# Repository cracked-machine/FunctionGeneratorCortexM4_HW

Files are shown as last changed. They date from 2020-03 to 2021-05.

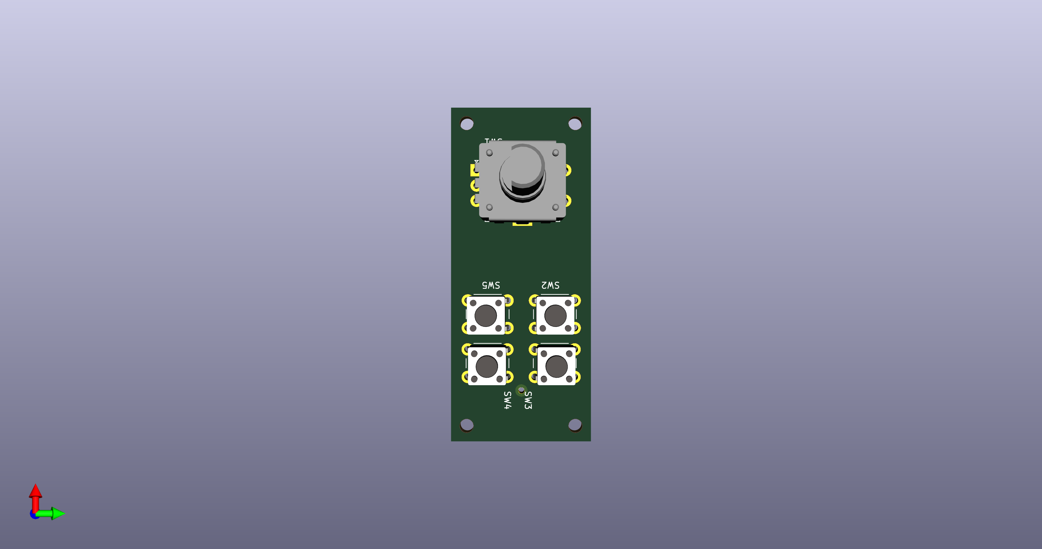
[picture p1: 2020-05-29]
HW/ControlsBoard/RevE/ControlsBoard/ControlsBoard.png

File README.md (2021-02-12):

## Cortex M4-based Function Generator (Hardware)
A function generator powered by STM32 G4.

Required Kicad Hardware library: https://github.com/cracked-machine/KicadLibrary

For details of the MCU configuration and firmware refer to [FunctionGeneratorCortexM4_SW](https://github.com/cracked-machine/FunctionGeneratorCortexM4_SW)

Note, RevB was the final design. RevC was not built and is an untested future proposal. 

### System Overview

Input signals can be used as a trigger, capturing on voltage level or edge detection.

DAC1 synthesises the main output signal waveform and sends it to a voltage gain amplifier ([LTC6910-3](https://www.analog.com/media/en/technical-documentation/data-sheets/6910fb.pdf)). The signal is then mixed with the DC offset signal from DAC2. The signal is then passes through a lowpass filter to remove any high frequency noise.

DAC2 is a DC signal 0-3.3V. This is sent to a buffer and inverting buffer. Either output is selected using the MCU-controlled SPDT switch IC ([TS12A12511DCNR](http://www.ti.com/lit/ds/symlink/ts12a12511.pdf)). This applies a software configurable DC offset between +3.3V and -3.3V to the main output signal.

DAC3 is an output signal synchronised to DAC1 to be used for triggering purposes.



### Daughter boards ###

The display, controls and i/o connectors are connected via daughter boards to the main board via ribbon cable. An example of the display daughter board and its ribbon cable can be seen in the video below:

https://www.instagram.com/p/CA5NSdBhmBY/?utm_source=ig_web_copy_link

### Power supply

##### Current Consumption:

|Component|Type|Current|
|---|----|---|
|STM32G4|MCU|42mA (max)|
|TL972|OPAMP|3.2mA (per amplifier)|
|LTC6910-3|PGA|4.9mA|
|TS12A12511|SPDT|1uA|
|74LVC1G3157|SPDT|35uA|
|LCD TFT|display|60mA|
|*__Total__*||*__120mA__*|

The 9V input is regulated down to 3.3V and 5V for the MCU and LCD display.

Dual supply for the VGA and opamps are provided using multiple [TPS60400](http://www.ti.com/lit/ds/symlink/tps60402.pdf) charge pumps. TPS60400 are rated at 60mA output but in testing was found to be less. Therefore, multiple TPS60400 were required to provide "point-of-load" regulation.

Additional filtering is provided at the MCU supply pins with L1 and L2 ferrite beads and C1-C12 bypass capacitors.

A midpoint reference 2.5V voltage is provided to the LTC6910-3 VGA using a  [TL431DBZ](https://www.ti.com/lit/ds/symlink/tl431.pdf) precision programmable reference.



### Limitations

The power supply limits the output to 9Vp-p. The output swing of the VGA limits this further.

The VGA output current is limited to ~25mA. This is also limited by the power supply.

Due to the settling time of the VGA, smooth sweeps between output amplitude levels using this IC was not possible. As such, the output is fixed to the maximum VGA level. Output amplitude control was handled by the firmware instead.

See [LTC6910-3](https://www.analog.com/media/en/technical-documentation/data-sheets/6910fb.pdf) datasheet for more information.

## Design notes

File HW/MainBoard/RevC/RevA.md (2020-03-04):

<link href="style.css" rel="stylesheet"></link>
<details>
<summary>
  <b>Functional requirements</b>
</summary>

- Output waveforms

  - Sine (wave table)
  - Step (varied DC according to step settings)
  - Square (toggled GPIO)
  - Triangle (DAC generator)
  - Sawtooth (DAC generator)
  - Pulse
  - PWM
  - Random/WhiteNoise (DAC generator)

- ~Output waveform MUX/switch to redirect output from MCU pins to Output BNC connector (if needed)~

- Output waveform frequency adjust (using rotary encoder)

- Output waveform DC bias adjust with ext. dual supply PGA (using rotary encoder)

- Output waveform gain/attenuation adjust (using rotary encoder)

- ~Redirect output to internal digital filter (FMAC)~

- Display to show active output waveform and attributes (frequency, DC bias, amplitude, relative gain)

- Input BNC connector for control voltage (to set the output waveform amplitude, trigger the output waveform)

- Output BNC connector for output waveform. 50Ω impedance.

</details>

<details>
<summary>
  <b>Top Level Design</b>
</summary>
  <p><center></p>
</details>

<details>
<summary>
  <b>PSU Component</b>
</summary>
  <p><center></p>
</details>

<details>
<summary>
  <b>Analog Front End Component</b>
</summary>
  <p><center></p>
</details>

<details>
<summary>
  <b>Schematic</b>
</summary>
  <p><a href="schema/FunctionGeneratorCortexM4.pdf">PDF Link</a></p>
<p><center></p>
<p><center></p>
<p><center></p>
<p><center></p>
</details>

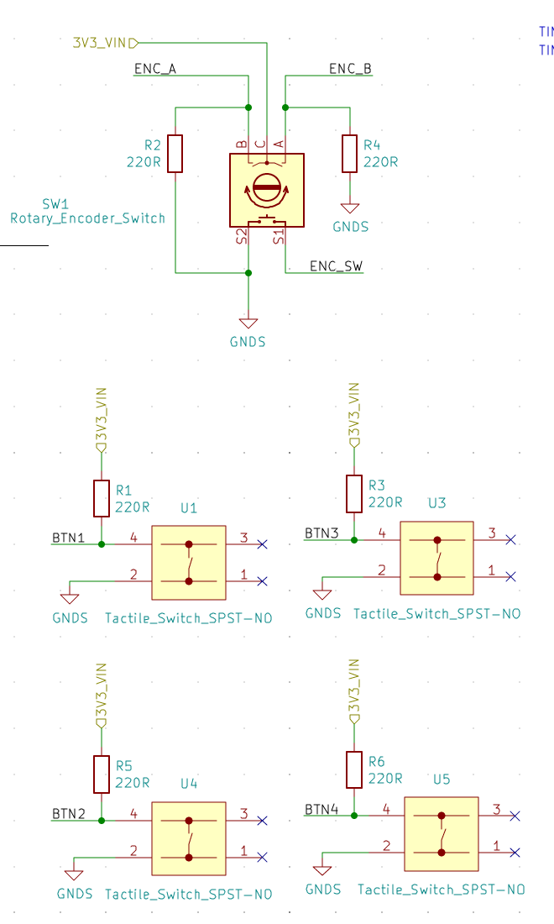
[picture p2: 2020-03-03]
FrontPanelInterface.png

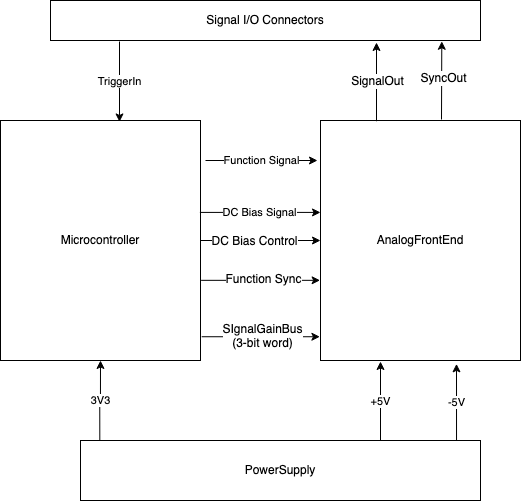
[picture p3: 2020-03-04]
HW/MainBoard/RevC/diagrams/FunctionGeneratorM4_TopLevel.png

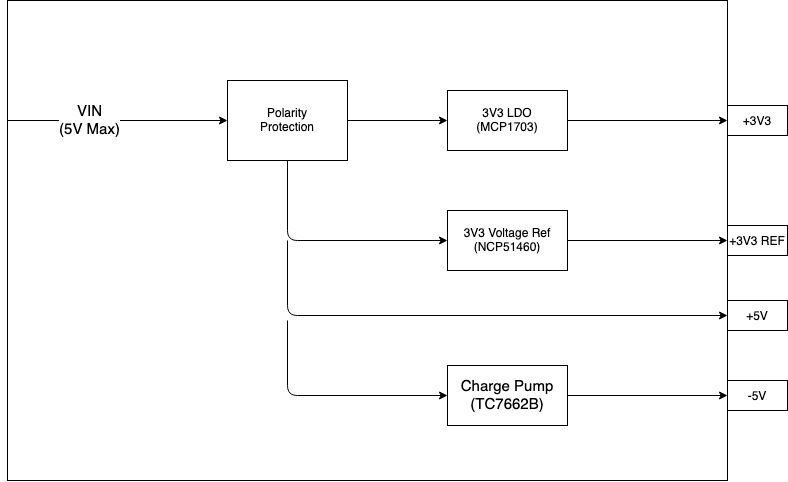
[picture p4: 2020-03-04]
HW/MainBoard/RevC/diagrams/FunctionGeneratorM4_PSU.png

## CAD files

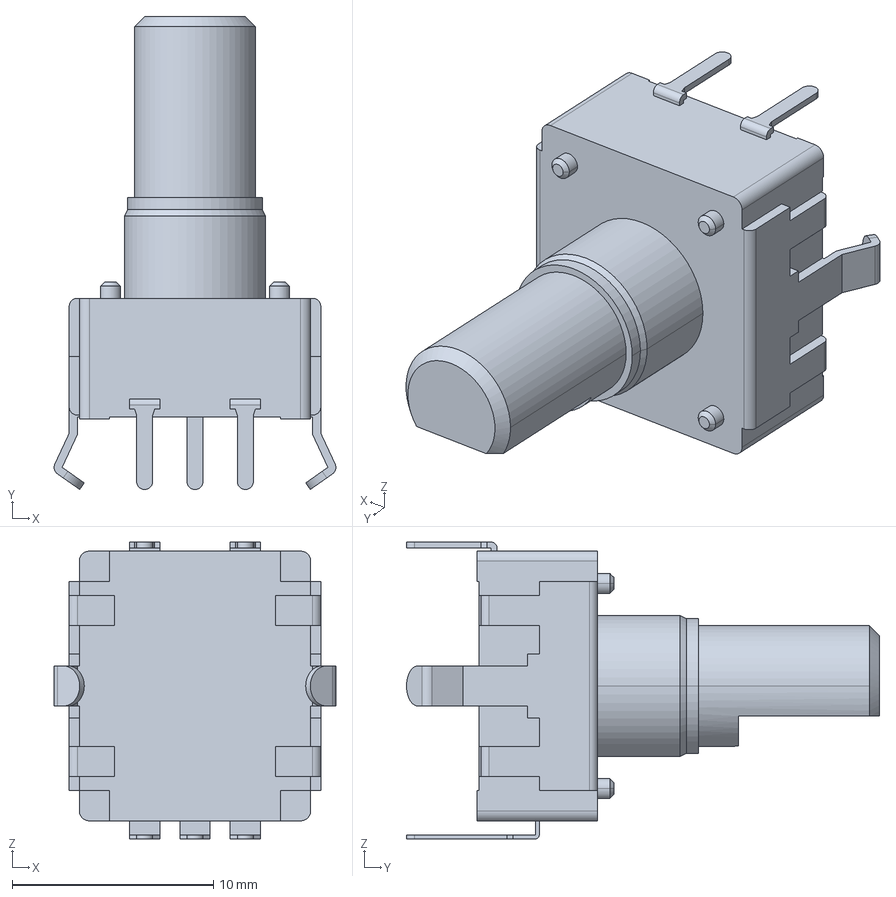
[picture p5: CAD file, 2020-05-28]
HW/ControlsBoard/RevE/ControlsBoard/pec12r-4x20f-sxxxx.stp
14.0 x 23.5 x 14.7 mm

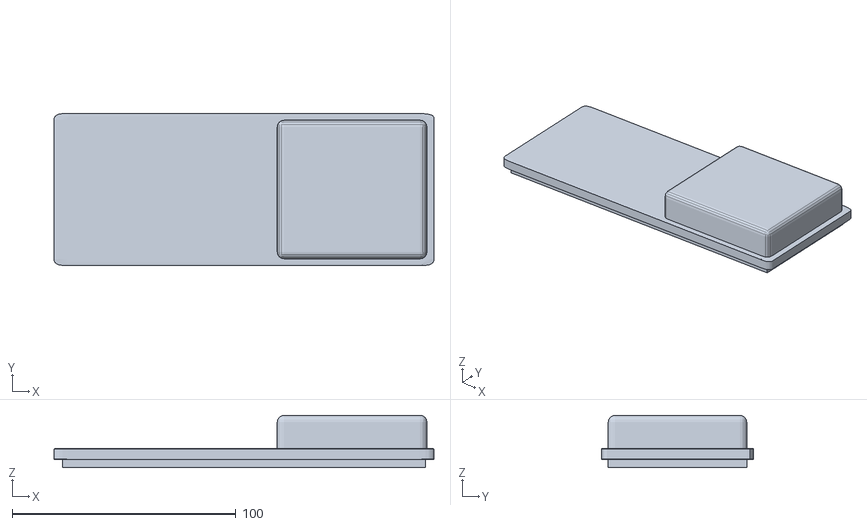
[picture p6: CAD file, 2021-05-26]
HW/FrontCover/FUNCGEN_COVER_final2.stl
170.0 x 68.0 x 23.4

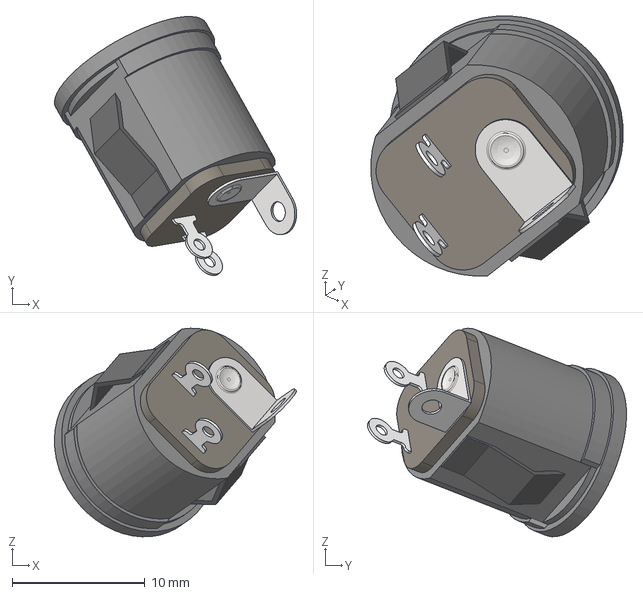
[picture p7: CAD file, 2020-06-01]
HW/Panels/BackPanel_Small/BackPanel_Small/datasheets/dc-jack_5.5x2.1.stp
18.2 x 19.5 x 15.7 mm

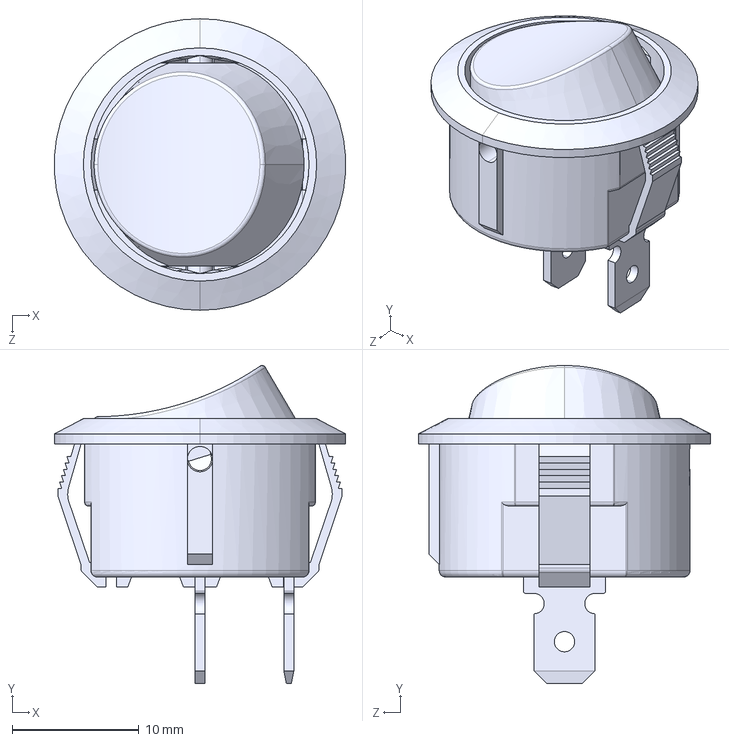
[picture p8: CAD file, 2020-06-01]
HW/Panels/BackPanel_Small/BackPanel_Small/datasheets/19645_Wippschalter 1-polig 250V 12A.STEP
23.0 x 25.1 x 23.0 mm

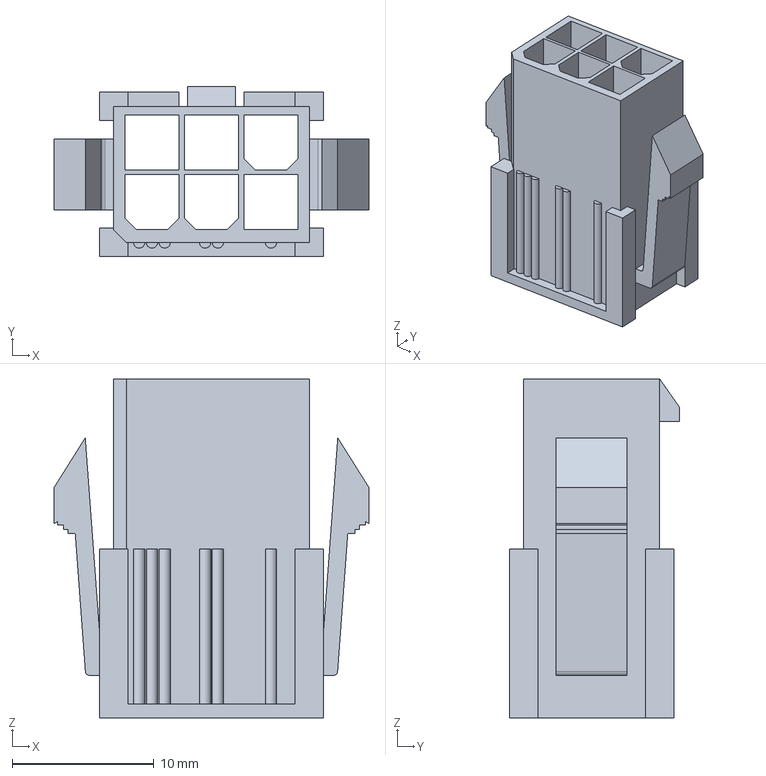
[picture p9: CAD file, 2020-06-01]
HW/Panels/BackPanel_Small/BackPanel_Small/datasheets/39012061.stp
22.2 x 12.0 x 23.9 mm

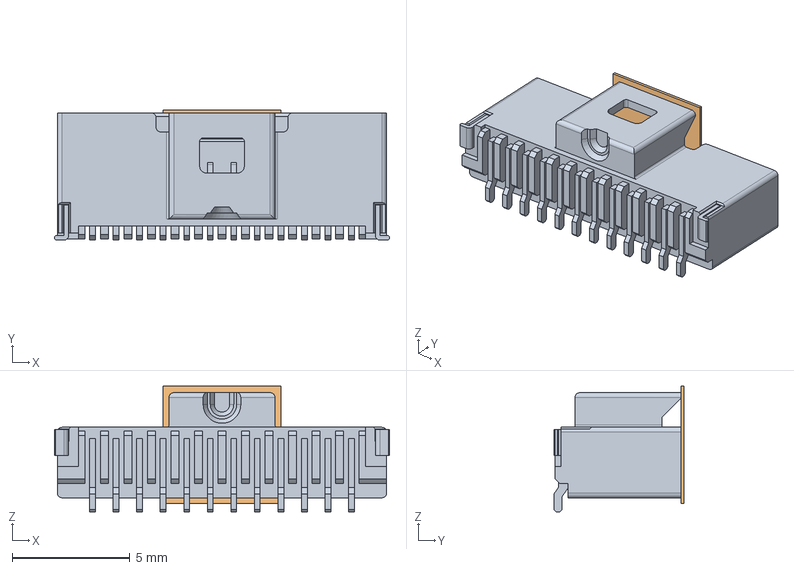
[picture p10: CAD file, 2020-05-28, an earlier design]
HW/ControlsBoard/RevD/ControlsBoard/5013311207.stp
14.2 x 5.54 x 5.35 mm

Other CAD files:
HW/FrontCover/FUNCGEN_COVER_final2.blend

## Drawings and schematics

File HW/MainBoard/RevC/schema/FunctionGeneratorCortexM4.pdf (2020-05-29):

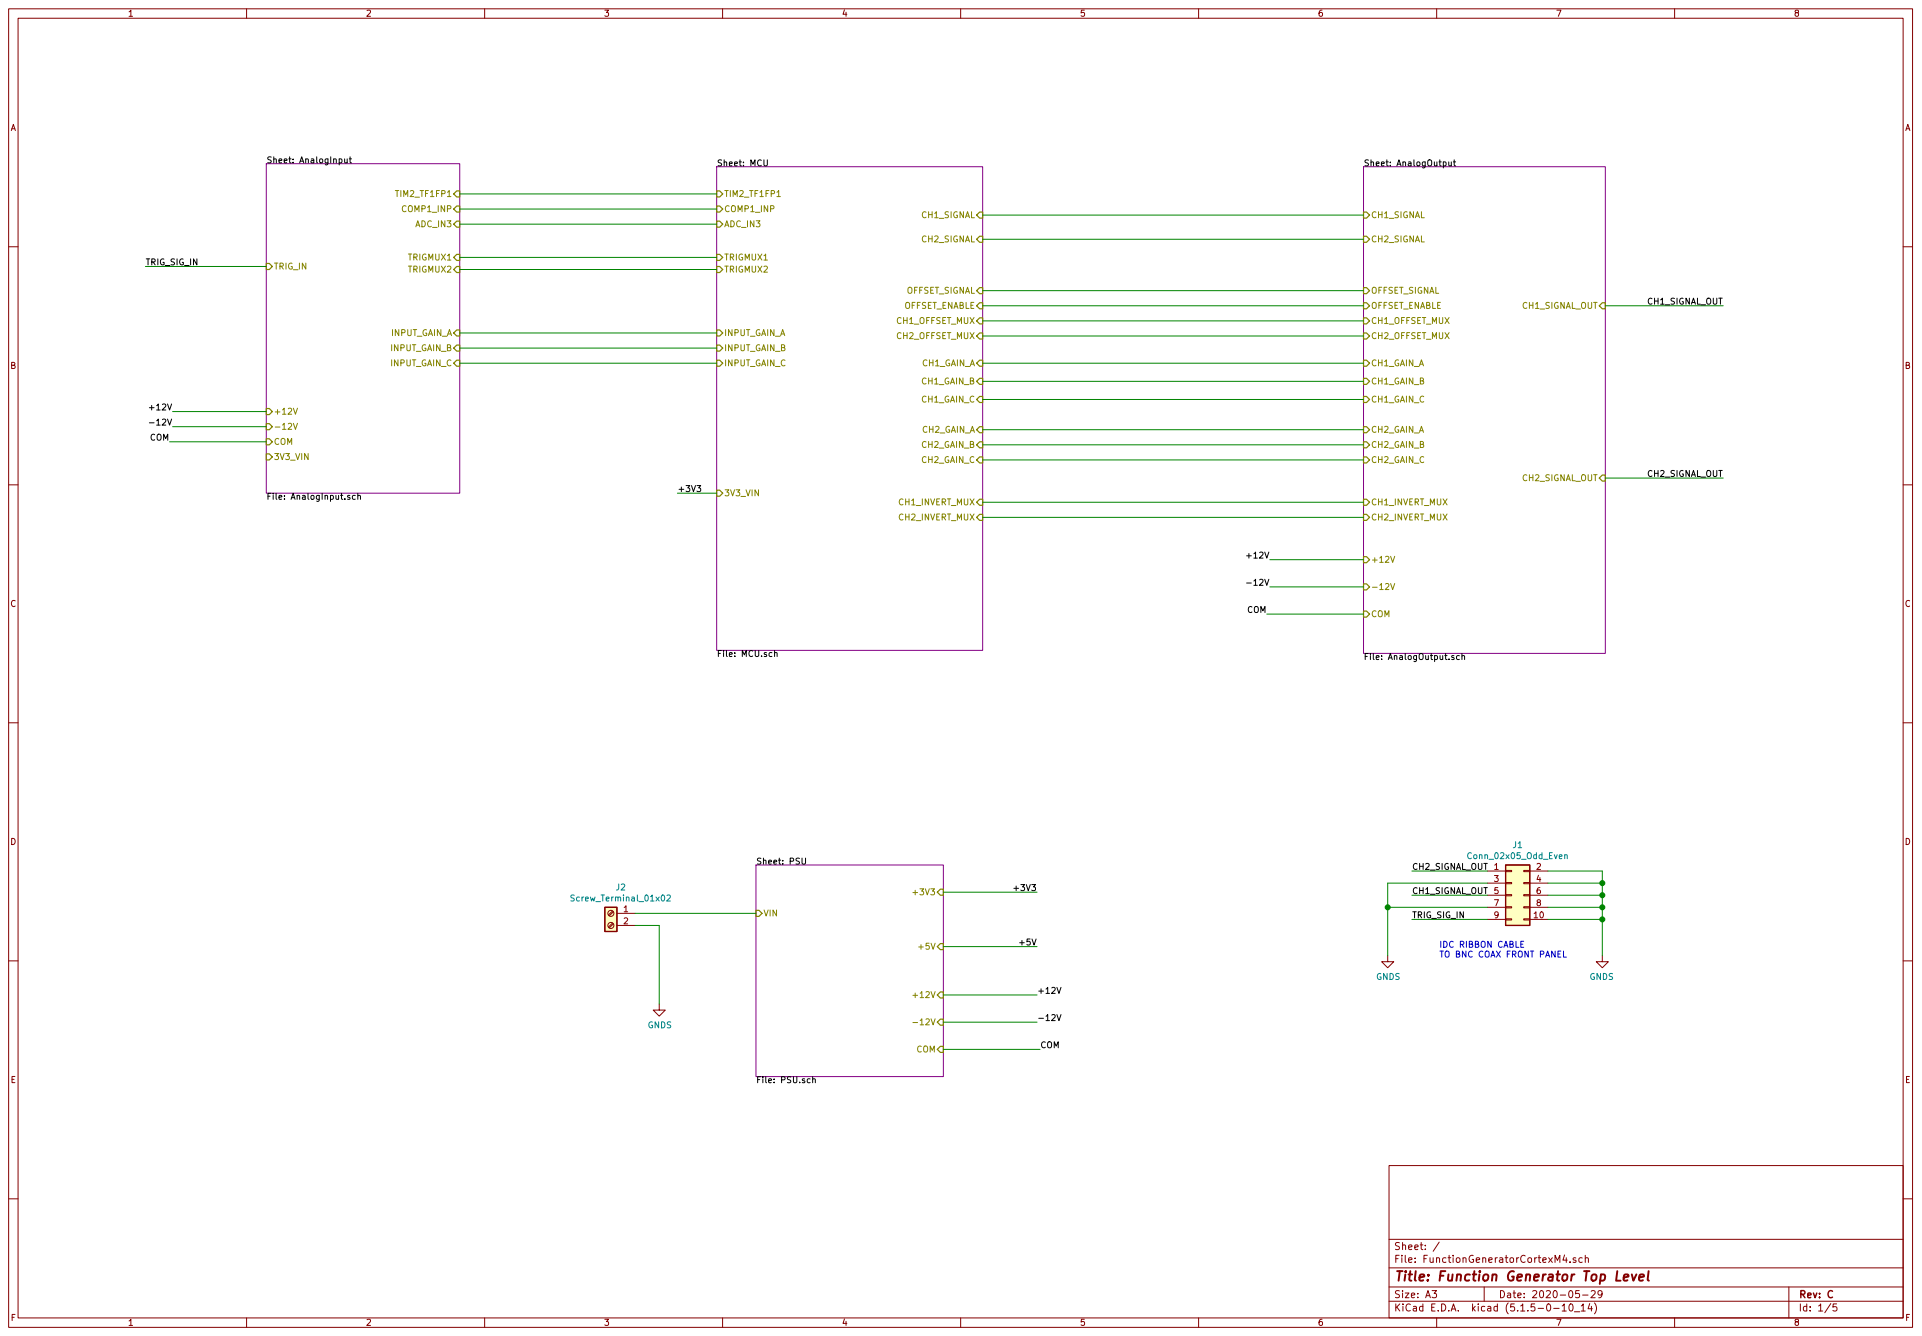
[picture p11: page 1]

Sheet: PSU
File: PSU.sch VIN

IDC RIBBON CABLE
TO BNC COAX FRONT PANEL

Id: 1/5 Title: Function Generator Top Level File: FunctionGeneratorCortexM4.sch Sheet: /

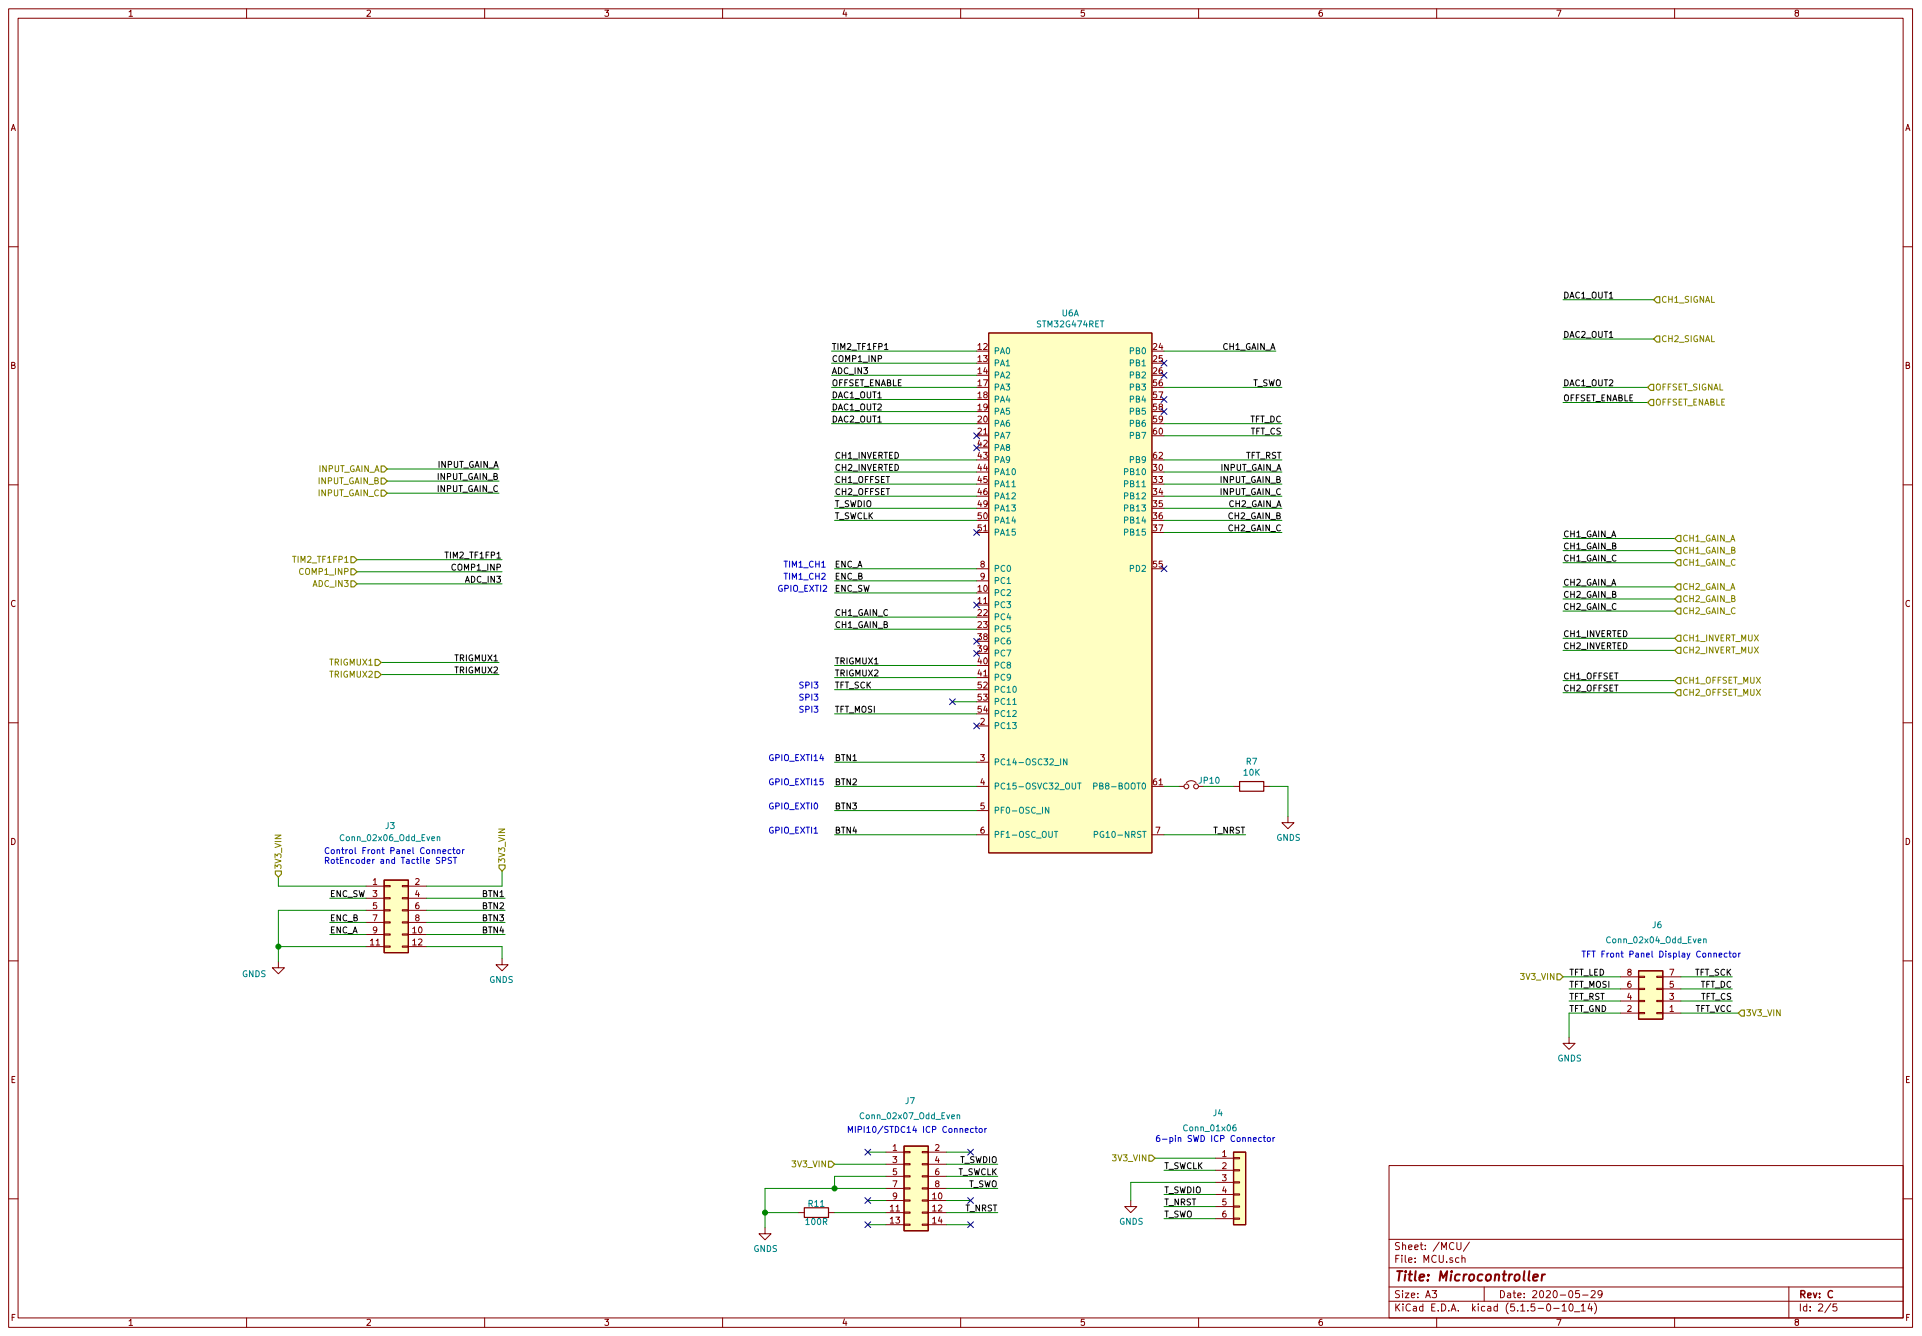
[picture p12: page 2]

TFT Front Panel Display Connector GPIO_EXTI2 GPIO_EXTI14 GPIO_EXTI15 TIM1_CH2 TIM1_CH1 GPIO_EXTI0 GPIO_EXTI1 SPI3 SPI3 SPI3

6-pin SWD ICP Connector MIPI10/STDC14 ICP Connector Control Front Panel Connector RotEncoder and Tactile SPST

Id: 2/5 Title: Microcontroller File: MCU.sch Sheet: /MCU/

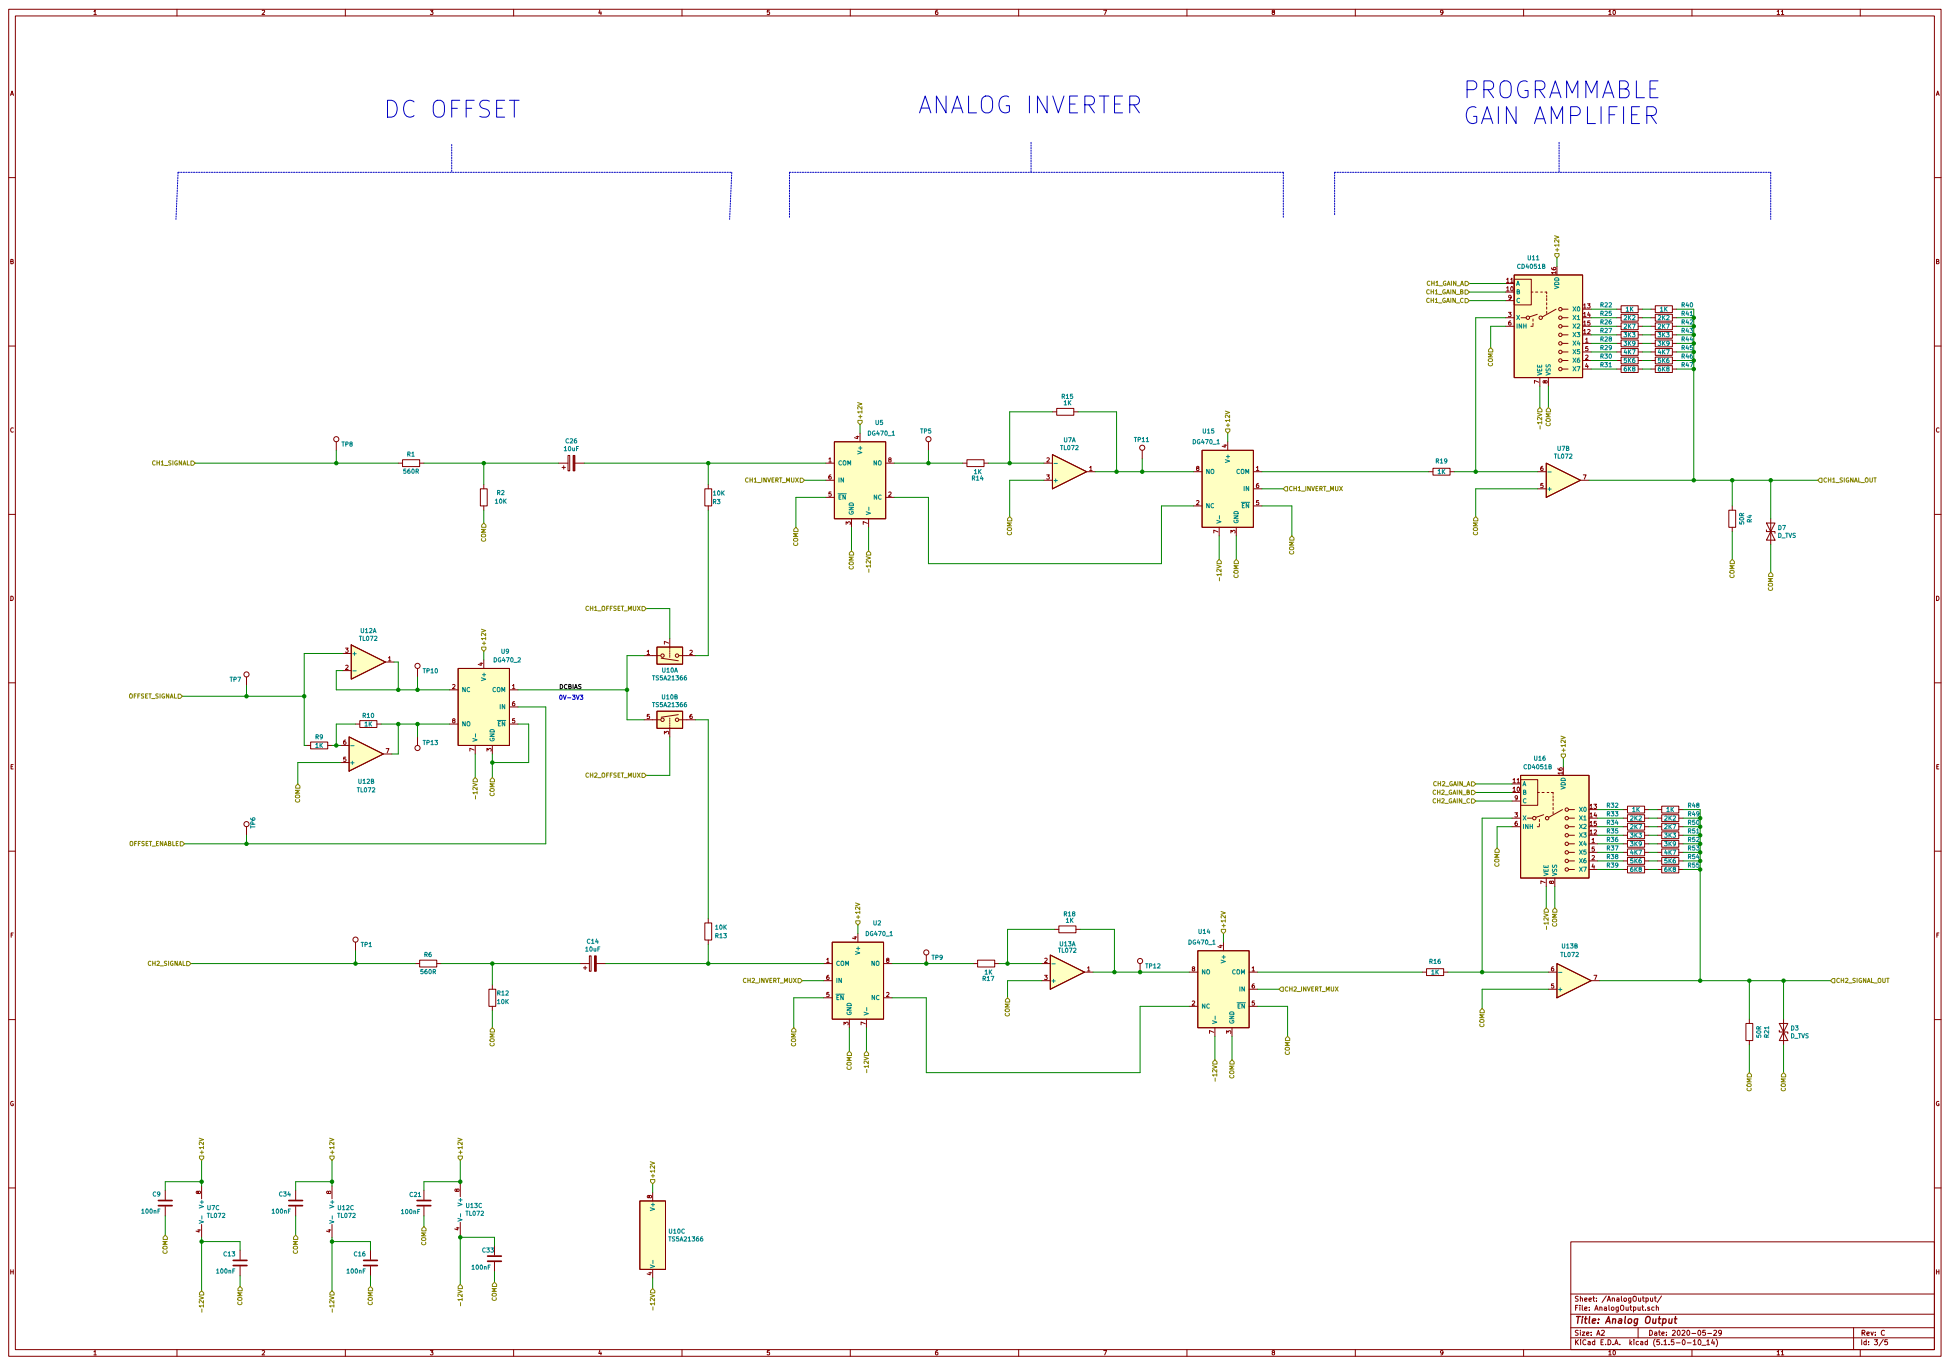
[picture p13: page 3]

Sheet: /AnalogOutput/
File: AnalogOutput.sch
Id: 3/5 Title: Analog Output

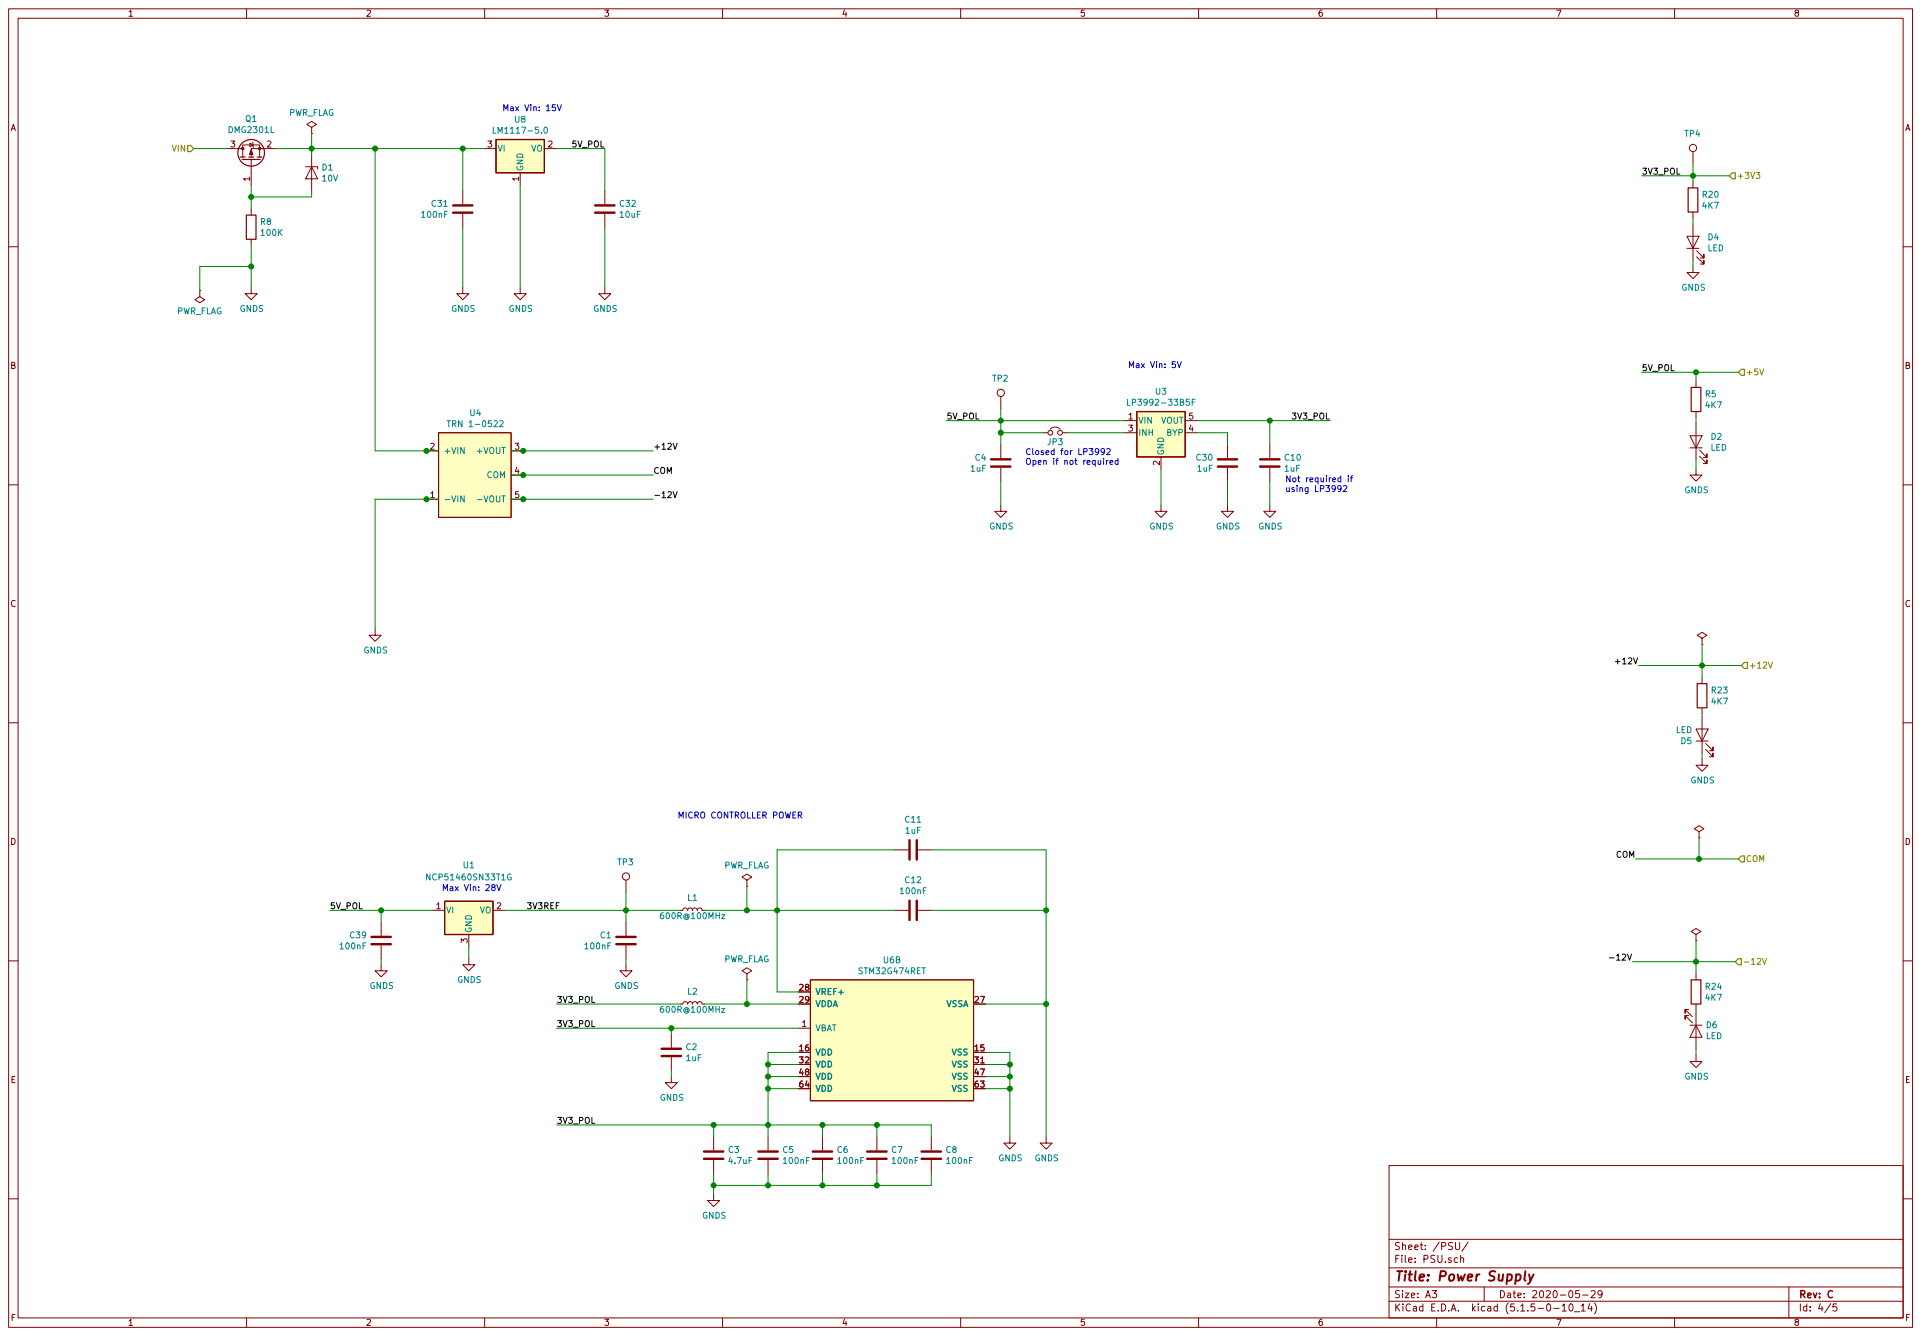
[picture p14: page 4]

using LP3992 Max Vin: 5V MICRO CONTROLLER POWER Max Vin: 28V

Closed for LP3992 Open if not required

Id: 4/5 Title: Power Supply

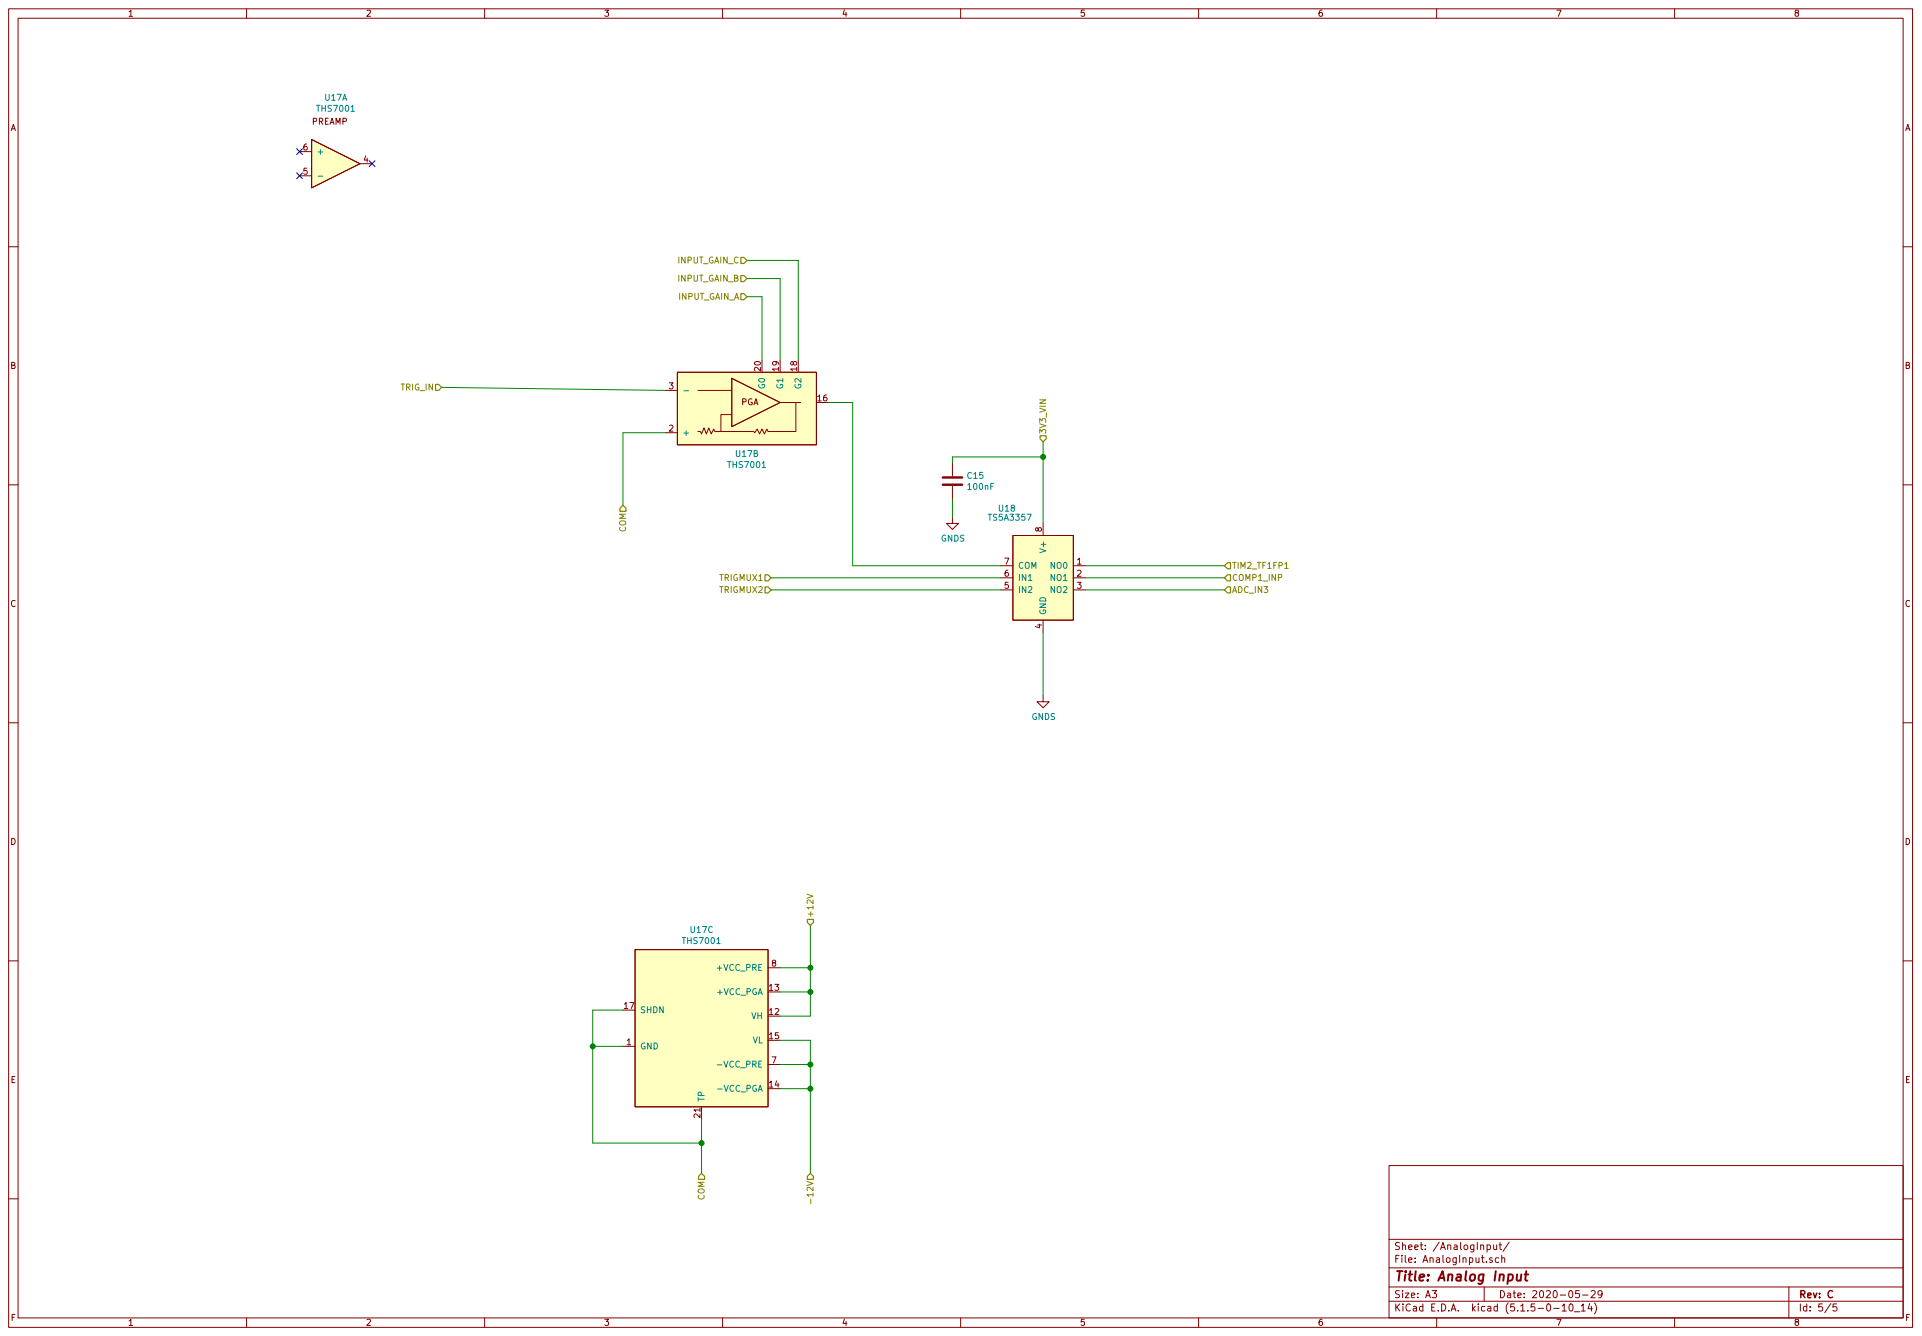
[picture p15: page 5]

File: AnalogInput.sch
Id: 5/5 Title: Analog Input

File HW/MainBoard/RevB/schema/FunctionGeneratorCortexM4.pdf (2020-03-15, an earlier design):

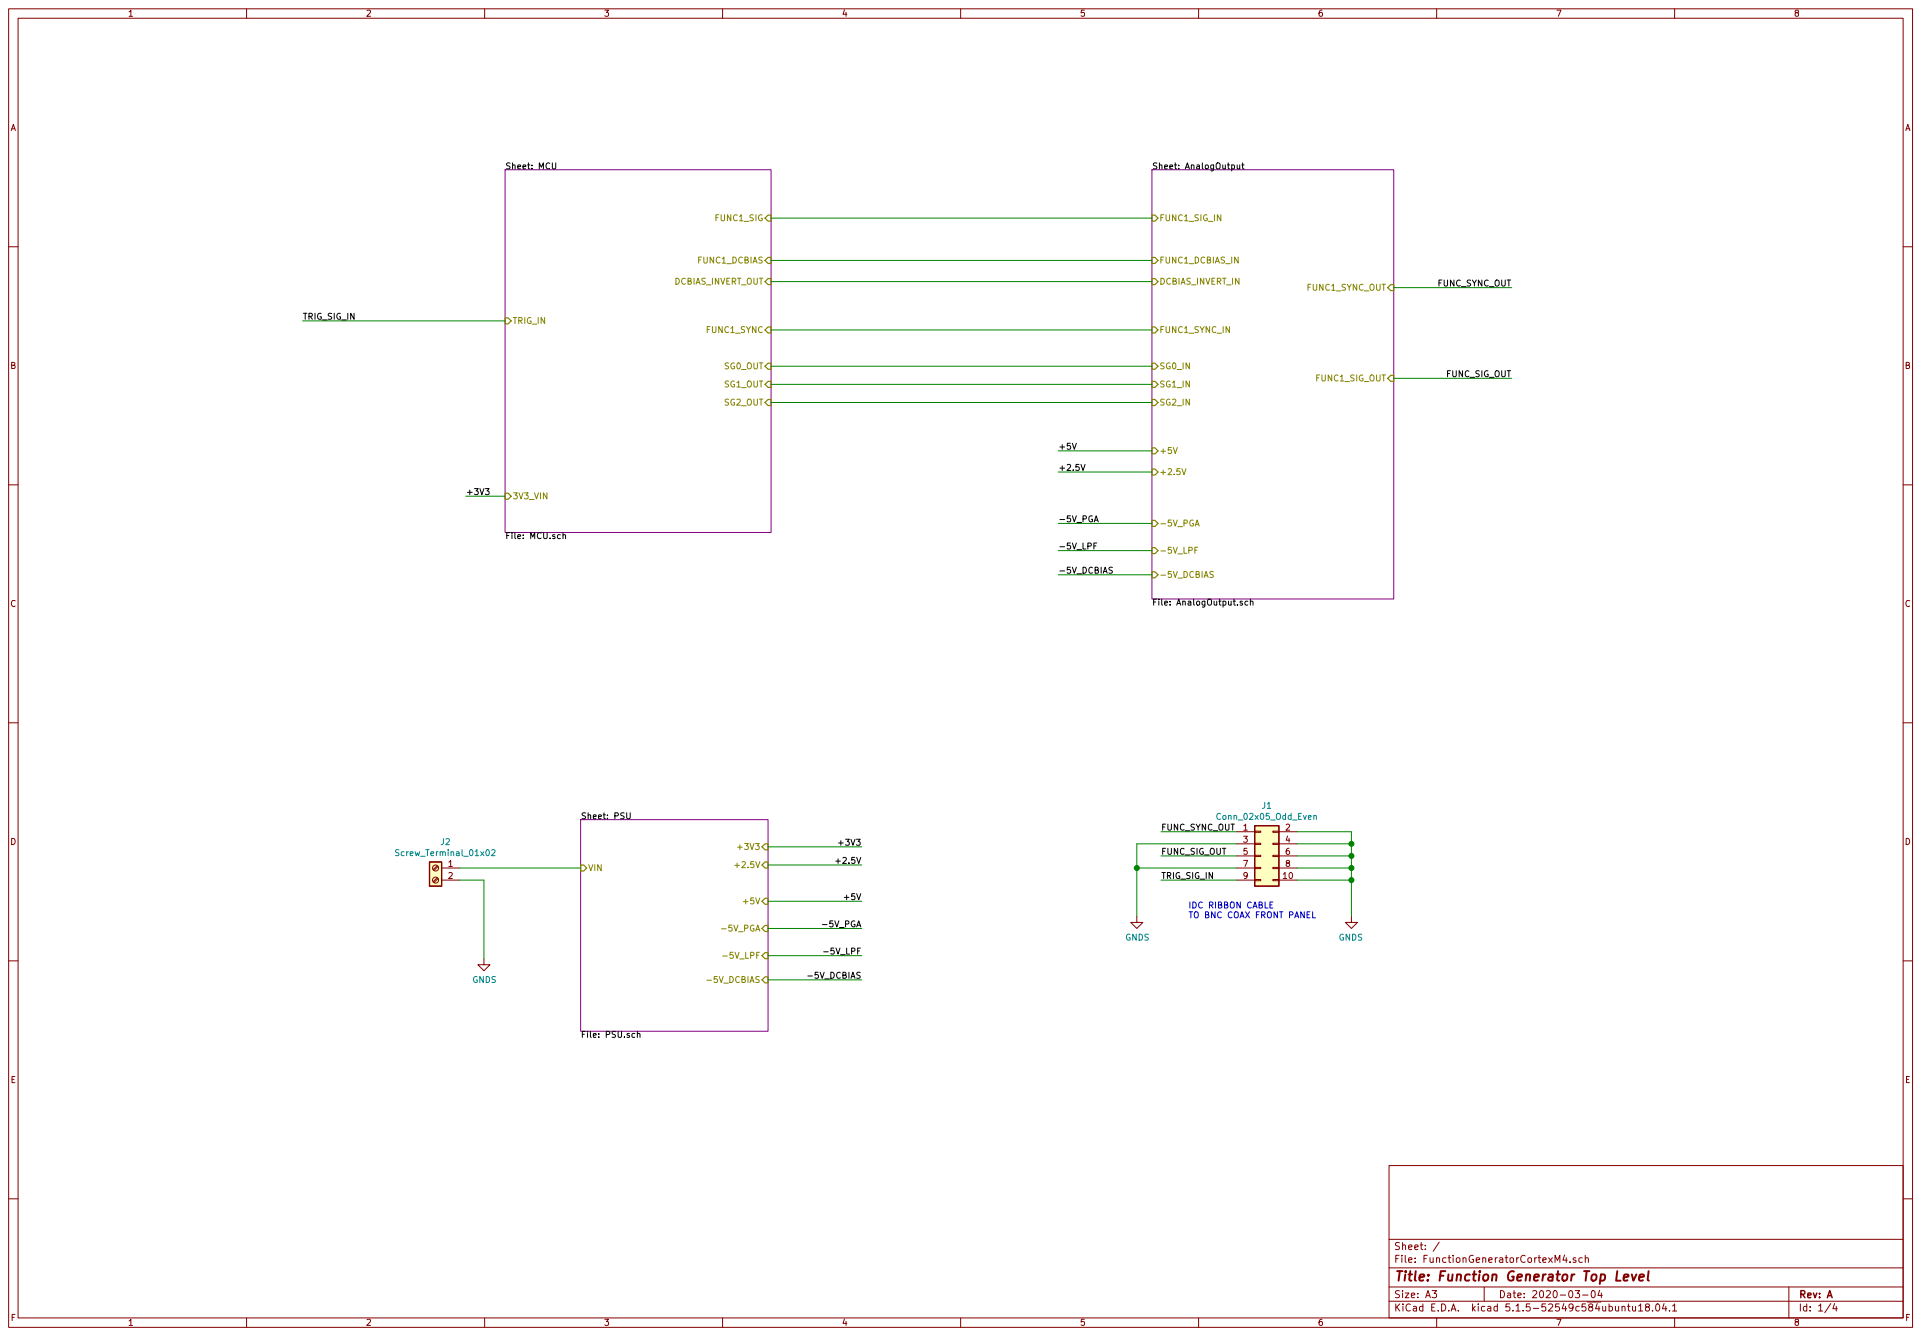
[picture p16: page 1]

Sheet: PSU
File: PSU.sch VIN

IDC RIBBON CABLE
TO BNC COAX FRONT PANEL

Id: 1/4 Title: Function Generator Top Level File: FunctionGeneratorCortexM4.sch Sheet: /

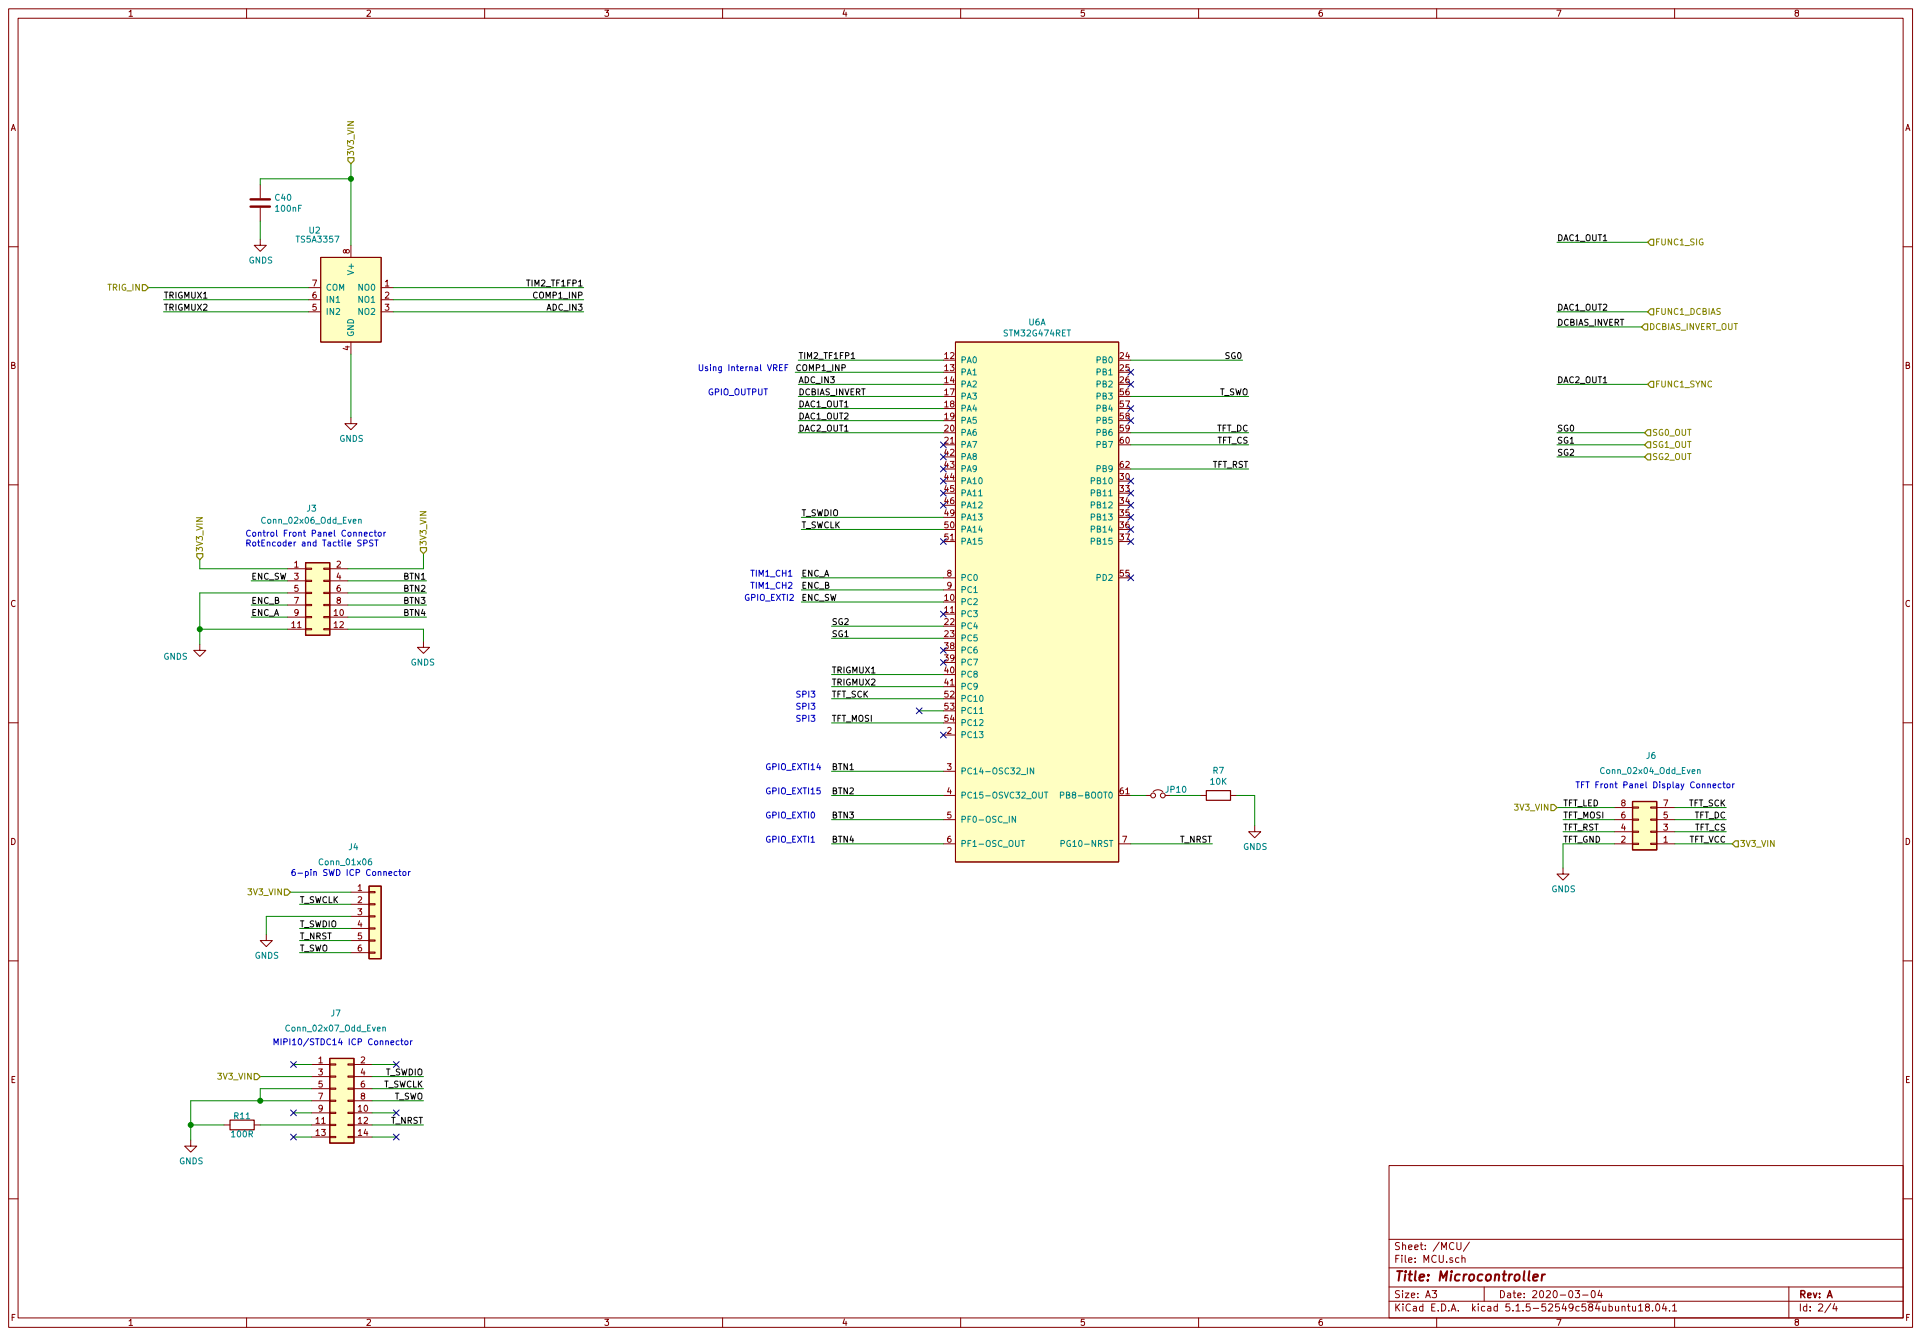
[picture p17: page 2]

Control Front Panel Connector RotEncoder and Tactile SPST

6-pin SWD ICP Connector MIPI10/STDC14 ICP Connector

Id: 2/4 Title: Microcontroller File: MCU.sch Sheet: /MCU/

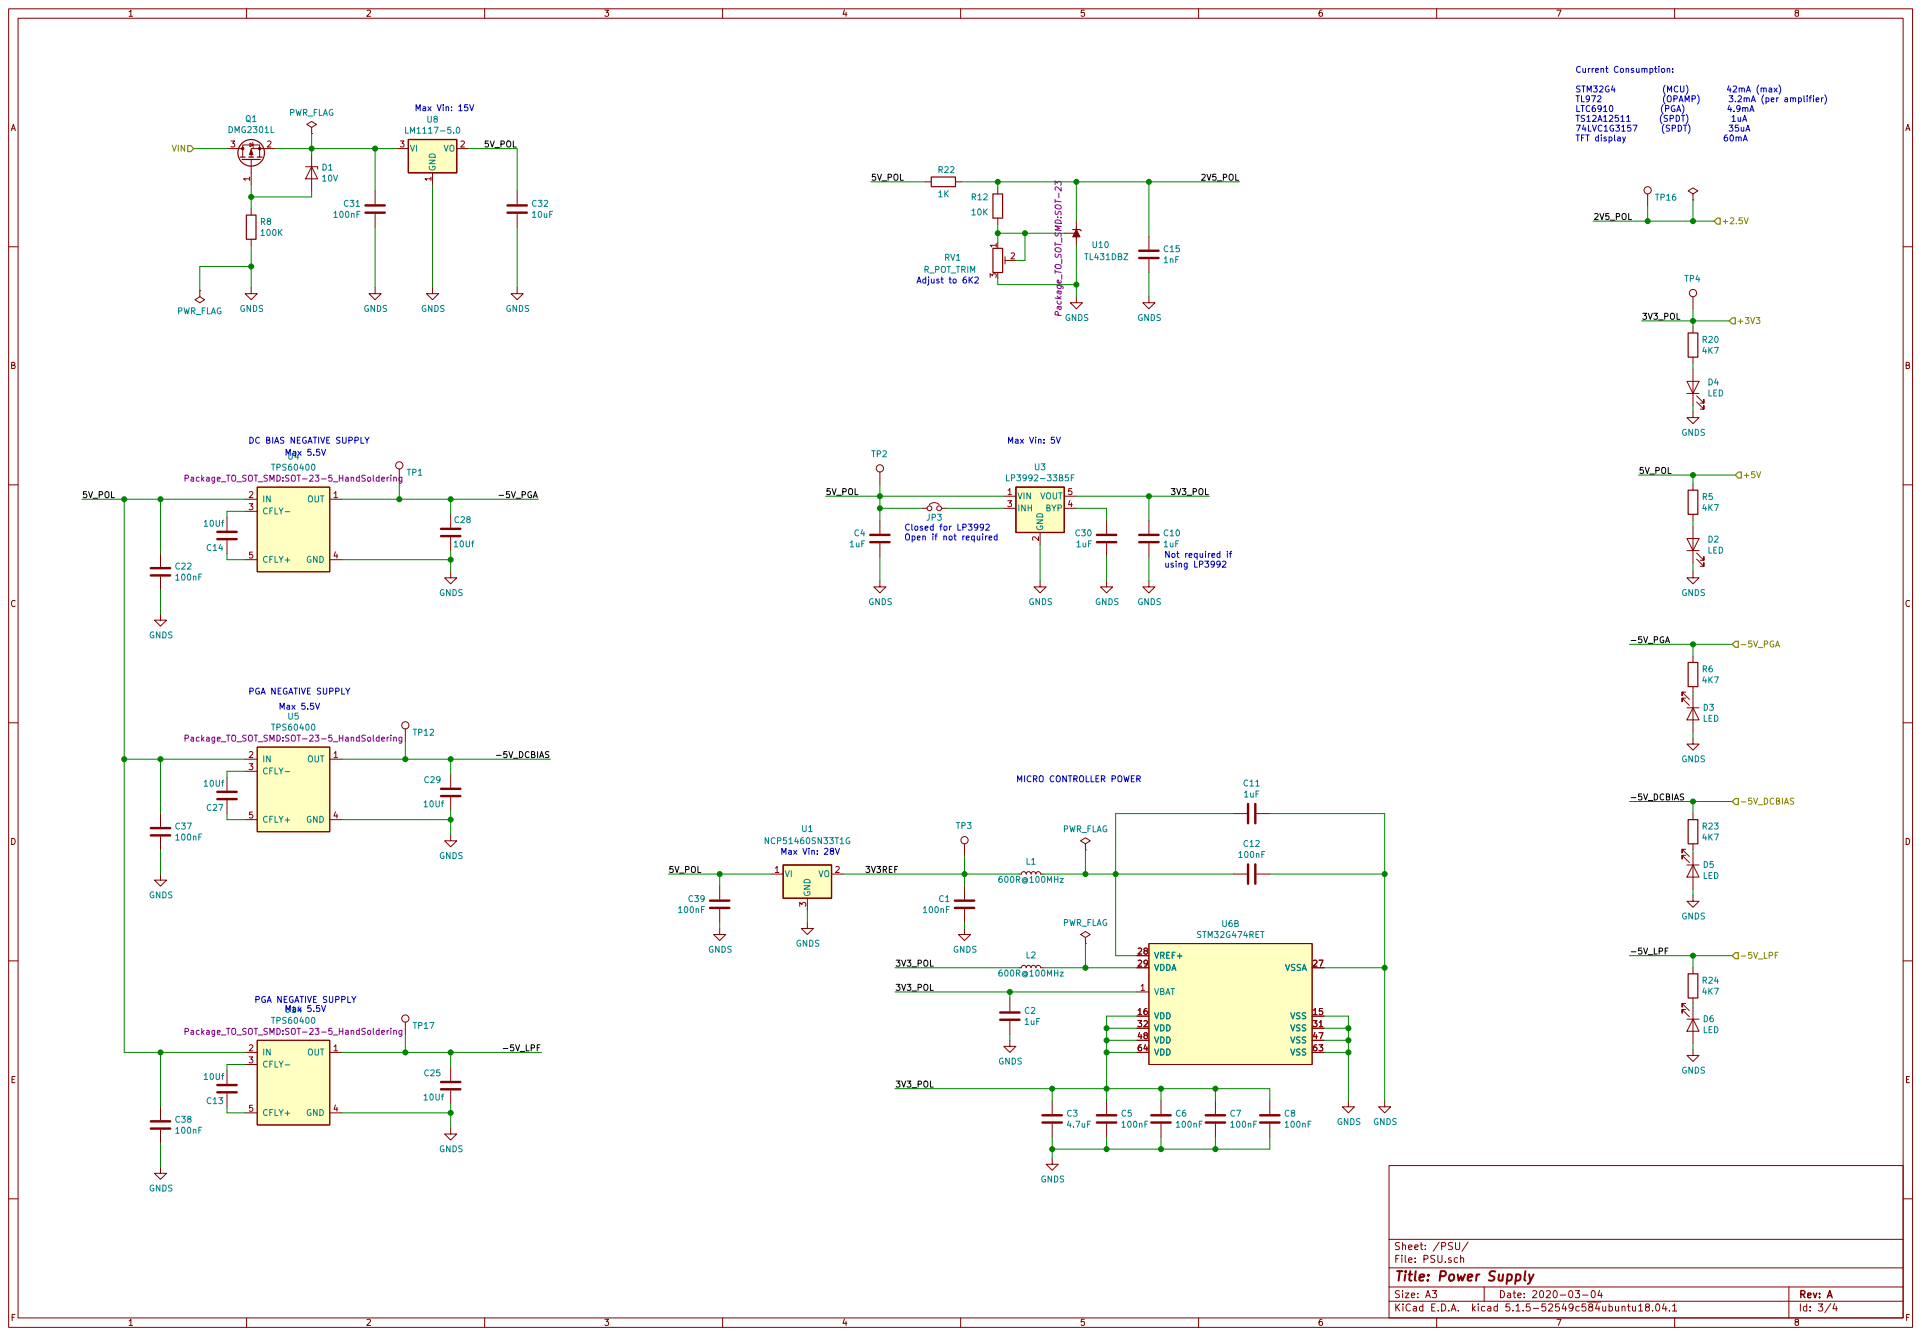
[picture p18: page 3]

using LP3992 Closed for LP3992 Open if not required

Id: 3/4 Title: Power Supply

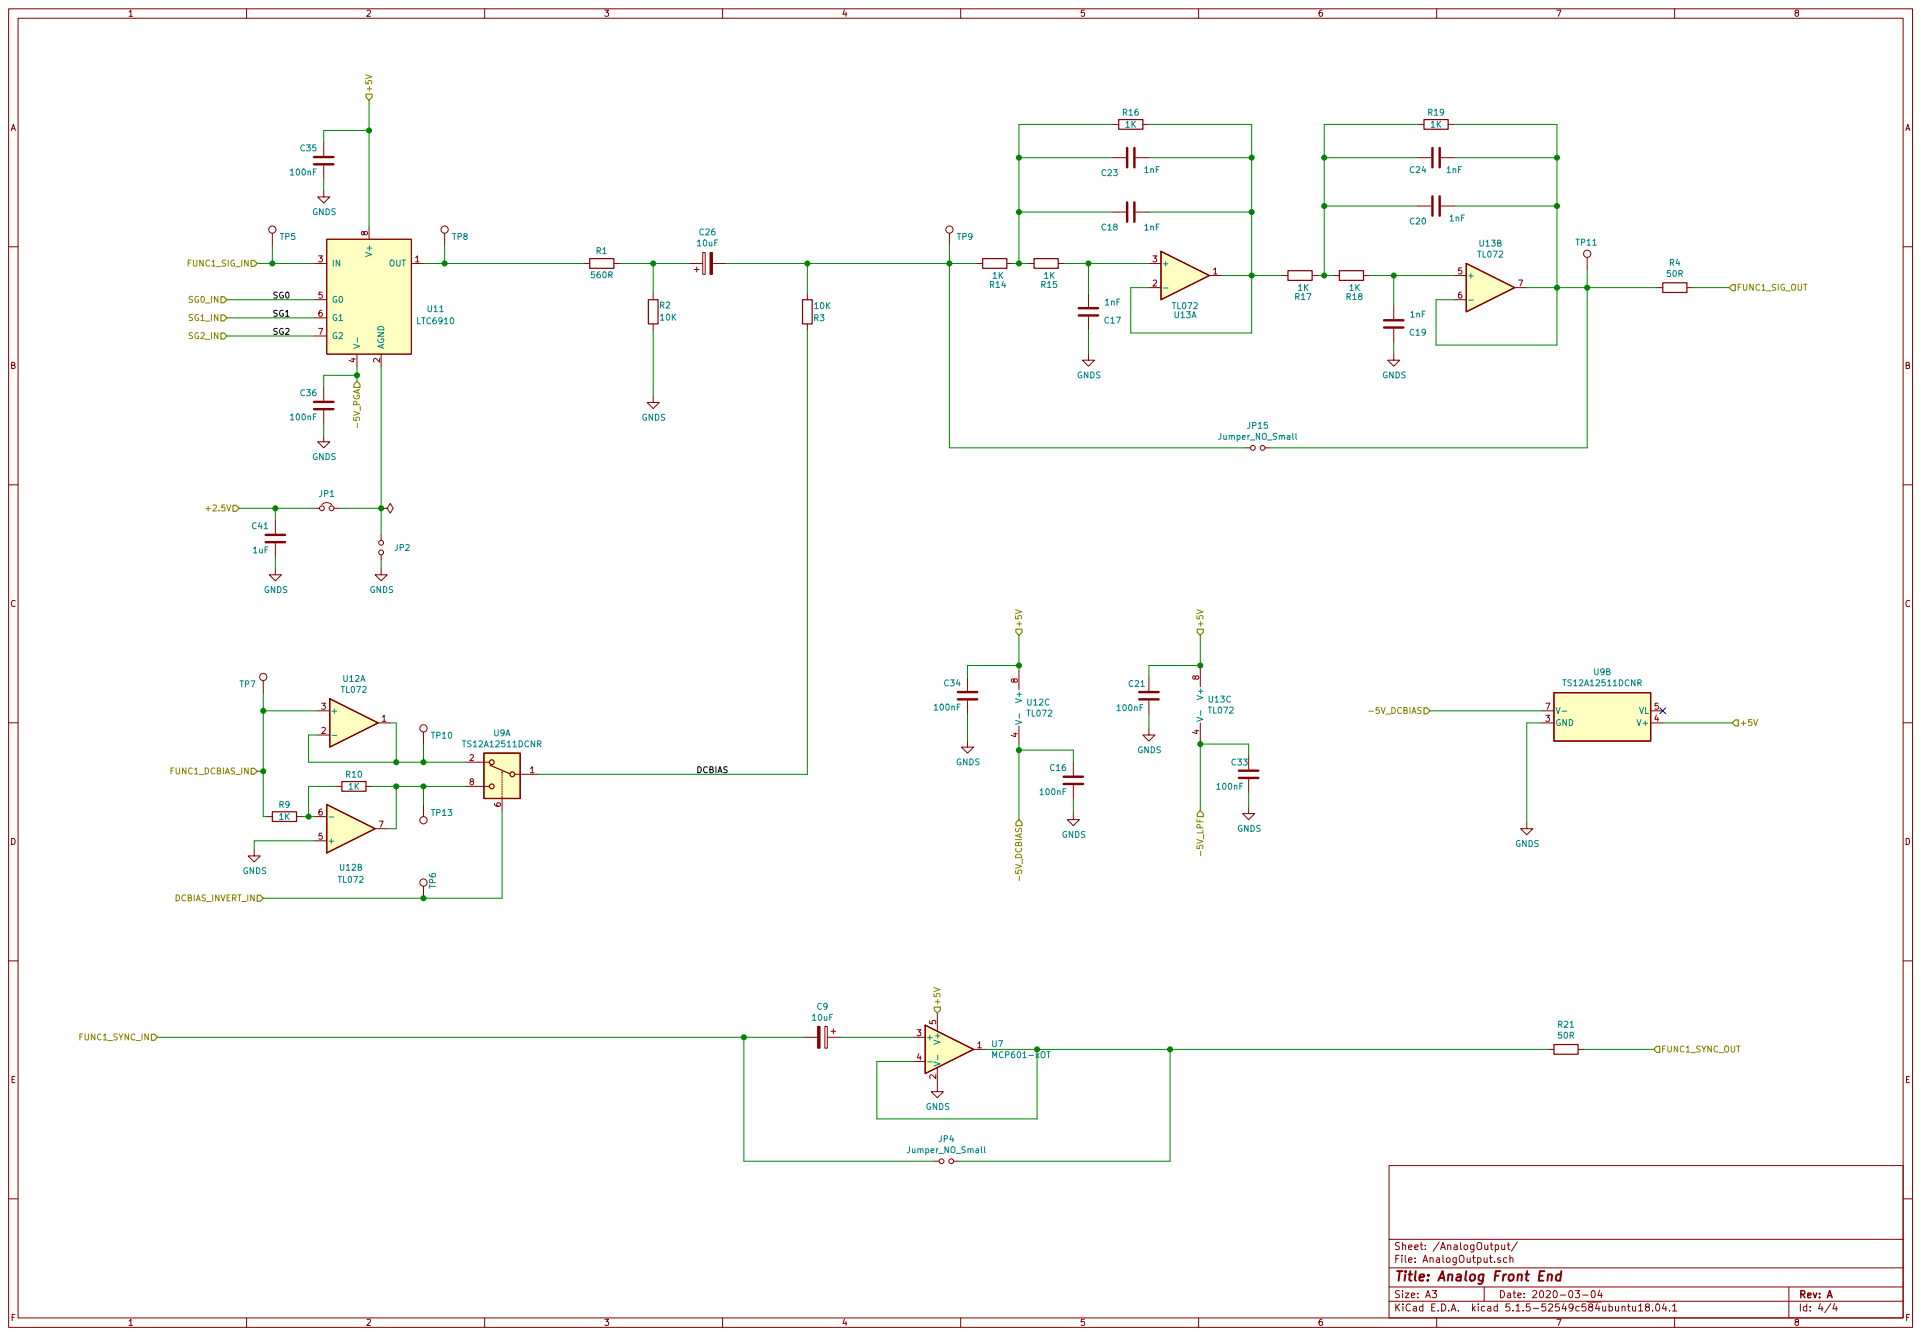
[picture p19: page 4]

Sheet: /AnalogOutput/
File: AnalogOutput.sch
Id: 4/4 Title: Analog Front End

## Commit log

2020-03-02 HW UPDATE
    - Added PSU block
    - Added MCU block
    [FunctionGeneratorCortexM4.kicad_pcb, FunctionGeneratorCortexM4.sch, MCU.sch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]
2020-03-03 hw update
    - Added MCU section
    [AnalogOutput.sch, FunctionGeneratorCortexM4.sch, MCU.sch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]
2020-03-03 Finished Schema
    [AnalogOutput.sch, FunctionGeneratorCortexM4.sch, MCU.sch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]
2020-03-03 hw update
    Added bypass jumper for output filter
    [AnalogOutput.sch]
2020-03-03 hw update
    added passives to dc bias stage
    [AnalogOutput.sch]
2020-03-03 Completed RevA layout
    [AnalogOutput.sch, FunctionGeneratorCortexM4.sch, MCU.sch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]
2020-03-04 Finished RevA Layout
    Dummy STMCubeMX project included in SW dir
    [AnalogOutput.sch, FunctionGeneratorCortexM4.kicad_pcb, MCU.sch]
2020-03-04 updated RevA
    Generated GERBERS
    [AnalogOutput.sch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]
2020-03-04 Added Schema PDF
    Added to RevA.md
    [AnalogOutput.sch, FunctionGeneratorCortexM4.sch, MCU.sch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]
2020-03-13 Added front panel boards
    [AnalogOutput.sch, DisplayBoard.kicad_pcb, DisplayBoard.sch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]
2020-03-13 Started HW RevB
    [AnalogOutput.sch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]
2020-03-14 REVB Update
    - Changed TRIGIN J5 header to 2.54mm
    - Changed IO J1 header to 2x05
    - Added second charge pump IC
    - Changed analog output circuit
    [FunctionGeneratorCortexM4.sch, MCU.sch, PSU.sch]
2020-03-14 Replaced LDO
    changed SOT223 (MCP1703) to SO23-5 (LP3992)
    [PSU.sch]
2020-03-14 Modified PowerSupply section
    - Added +2.5V ref
    - Added Vin->5V LDO
    [AnalogOutput.sch, FunctionGeneratorCortexM4.sch, PSU.sch]
2020-03-15 REVB DRAFT LAYOUT
    [AnalogOutput.sch, FunctionGeneratorCortexM4.kicad_pcb, PSU.sch]
2020-03-15 OPTIMIZED REVB LAYOUT
    [AnalogOutput.sch, FunctionGeneratorCortexM4.kicad_pcb, FunctionGeneratorCortexM4.sch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]
2020-03-15 Final RevB Layout completed
    [AnalogOutput.sch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]
2020-03-31 updated front panel board layouts
    [Controls.sch, ControlsBoard.kicad_pcb, ControlsBoard.sch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]
2020-04-06 Added Revb designs for I/O and control panels
    [Controls.sch, ControlsBoard.kicad_pcb, ControlsBoard.sch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]
2020-04-06 updated control panel
    [ControlsBoard.kicad_pcb, IOBoard.kicad_pcb]
2020-04-12 Created FrontPanel drawing
    [ControlsBoard.kicad_pcb, IOBoard.kicad_pcb]
2020-05-18 Added RevC Control Panel
    Uses 55mm x 20mm PCB outline
    Uses 6mm switches rather than 12mm
    [Controls.sch, ControlsBoard.kicad_pcb, ControlsBoard.sch]
2020-05-26 Created RevC - MainBoard and ControlBoard
    [AnalogOutput.sch, ControlsBoard.kicad_pcb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]
2020-05-28 Created RevD using PicoClasp p1.0 connector
    [5013311207.stp, Controls.sch, ControlsBoard.kicad_pcb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]
2020-05-29 Updated MainBoard RevC
    - Block diagram and connections completed on schematic
    - Need to check MCU pin availability
    [AnalogInput.sch, AnalogOutput.sch, FunctionGeneratorCortexM4.sch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]
2020-05-29 Changed OFFSET SPDT to DG470
    [AnalogOutput.sch, FunctionGeneratorCortexM4.sch]
2020-05-29 Added two-series resistors in PGA feedback
    [AnalogInput.sch, AnalogOutput.sch, FunctionGeneratorCortexM4.sch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]
2020-05-29 Created RevE ControlBoard to use 2.54 SMD header
    Header is at the top of the board to let buttons and encoder be closer together
    [AnalogOutput.sch, Controls.sch, ControlsBoard.kicad_pcb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]
2020-05-30 updated front panel svg
    [ControlsBoard.kicad_pcb, FrontPanel.kicad_pcb, FrontPanel.sch]
2020-05-30 Created Front Panel board layout
    [AnalogInput.sch, AnalogOutput.sch, FrontPanel_Small.kicad_pcb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]
2020-06-01 Created FrontPanel layout
    [19645_Wippschalter 1-polig 250V 12A.STEP, 39012061.stp, BackPanel_Small.kicad_pcb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]
2020-06-03 update analog input schema
    [AnalogInput.sch, AnalogOutput.sch]
2020-06-08 Added OutputAmplifier stage board
    [OutputAmplifier.kicad_pcb, OutputAmplifier.sch, SignalOutputGainStage.sch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]
2020-09-13 updated readme
    -- Added power supply section
2021-05-26 Added 3D models for front cover
    [FUNCGEN_COVER_final2.blend, FUNCGEN_COVER_final2.stl]

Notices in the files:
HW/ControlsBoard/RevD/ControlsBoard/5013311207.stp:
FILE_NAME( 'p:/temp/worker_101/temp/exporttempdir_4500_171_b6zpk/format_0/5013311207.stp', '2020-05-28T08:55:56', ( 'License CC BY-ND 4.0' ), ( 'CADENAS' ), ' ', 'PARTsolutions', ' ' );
